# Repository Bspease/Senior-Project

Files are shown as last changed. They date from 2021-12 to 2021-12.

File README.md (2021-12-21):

# Senior-Project

“The Traveling Musician” is the name of the device that travels up and down any piano and plays music. After setting it up, the traveler will start playing the song programmed into it after a
button press until the song has been completed.

This was my 2021 Summer-Fall Senior Project to create a musical device that can play a piano to some degree.

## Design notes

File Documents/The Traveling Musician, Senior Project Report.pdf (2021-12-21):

The Traveling Musician

A Senior Project Report

presented to

the Faculty of California Polytechnic State University

San Luis Obispo

In Partial Fulfillment

of the Requirements for the Degree

Bachelor of Science in Computer Engineering

By

Brian Pease

December 2021

## Table of Contents

Abstract | 3
Introduction | 4
Stakeholders | 4
Project Goals and Objectives | 4
Project Deliverables | 5
Project Outcomes | 5
Background | 5
Formal Project Definition | 6
Customer Requirements | 6
Engineering Requirements | 6
Customer Personas | 7
Use Case | 8
Design | 8
Base | 8
Runner | 10
Software | 14
System Testing and Analysis | 15
Conclusion and Future Work | 17
Reflection | 17
Bibliography | 19

Appendix | 20
Analysis of Senior Project Design | 20
Summary of Functional Requirements | 20
Primary Constraints | 20
Economic | 21
Original Estimated Cost | 21
Final Component Cost | 22
Final Bill For All Components | 22
Original Estimated Development Time | 23
Actual Development Time | 24
If manufactured on a commercial basis | 24
Manufacturability | 24
Sustainability | 25
Ethical | 25
Health and Safety | 25
Social and Political | 26
Development | 26

# Abstract

“The Traveling Musician” is the name of the device that travels up and down any piano and

plays music. After setting it up, the traveler will start playing the song programmed into it after a

button press until the song has been completed. Pressing the button again will have it repeat.

# Introduction

Musical instruments such as pianos, have periods of time of unuse. Whether this is because of

work, family, or time, pianos have downtime. This product serves to utilize the piano when it’s

not in use, to act more as background noise. There are pianos that can self-play, though this

product would be a cheaper alternative aimed for pianos that do not have this function.

## Stakeholders

Customers that would be potentially interested in this would be people who have mostly unused

pianos and would like to have background music without having to spend a lot for their piano to

be converted to a self-playing piano. The product could be used in smaller restaurants or within

family households. These customers would benefit from a cheaper alternative to automated play

and that is not difficult to set up.

## Project Goals and Objectives

The goal would be to play a song:

- Objective 1: Move to the correct key for the note
- Objective 2: Activate the correct solenoid for the note (white or black key)
- Objective 3: Play a simple song that requires little movement
- Objective 4: Play a normal song

## Project Deliverables

The main deliverable would be a device that goes up and down any piano in time to a song and

plays the proper notes.

## Project Outcomes

- More pianos being used in a casual environment
- Piano furniture (never played piano) becomes a feature for a house.
- Could inspire more piano players
- Create live piano music for movie usage without a pianist knowing how to play.

# Background

There has been work in the past that makes pianos “self-playable”, such as Edelweiss’s pianos.

This was accomplished by having solenoids with varying pressure under the striking lever,

mimicking a strike to the key and thus to the piano string. Having these solenoids allows for an

electronic means of activating them such as through an ipad. Prior to the Edelweiss piano, there

was also the pianola, a vacuum based self-playing piano popular in the late 19 century. The

pianola was a much more complex device since it required the use of specifically made paper

rolls for the music and required the mechanisms to be under a slight vacuum. A less extensive

and simpler way is using solenoids.

# Formal Project Definition

## Customer Requirements

- Be reasonably priced
- Easily placed and removed
- Plays a song
- Generally easy to use

## Engineering Requirements

Product Requirements Table

Spec Number | Parameter Description | Requirements | Tolerance | Risk | Compliance
1 | Seconds Off Beat | 1 sec | Max | H | T
2 | Note Travel Error Accuracy | 0.5 mm | Max | H | T
3 | Power | 6 W | Max | L | A, T
4 | Key Range | 7 Keys | Min | L | I

5 | Runner Height Size | 50 mm | Max | L | I
6 | Cost | $60 | Max | L | I
7 | Weight | 200 g | Target | L | T
8 | Set up time | 10 sec | Max | L | I

## Customer Personas

Nathan, a piano enthusiast, wants to explore capabilities not previously thought of in live piano

music. Effectively playing with three hands, the product will act as support to the piano player

Nathan. His students would also use it to ease them into playing with both hands. The robot

acting as the other hand.

Diego, a small business owner, has a piano for his customers but he finds that not many partake

in playing. He has considered hiring a part time musician but due to the covid situation he does

not want to eagerly spend. The device would allow him to have his piano be more in use, and

create a more vibrant environment for his customers.

Samantha, A piano owner, has frequent hangouts with friends, family members, and coworkers.

She loves the presence of a piano but never actually learned to play it. With the device she can

add more flavor to her house without breaking the bank.

## Use Case

The user would place the device on the piano. Situate the arduino and breadboard in front of the

base, ideally on the piano (off of the keys). Plug in the device to a wall outlet and situate the

device on top of a C key with at least the next octave under the wooden base. The user would

then simply press the button on the breadboard after they pre-programmed their songs prior in

order to hear their song.

# Design

The design process was broken up into three different parts. The first part pertained to the

design of the base or structure that held the device; The second was the design of the actual

“runner” or the piece that holds the solenoids and parts; The third was the software design.

## Base

The base was only difficult to design mainly because it had to work for any piano of any size. I

had access to three different pianos during the summer when I was working on this part. A

regularly sized grand piano, electric piano, and a medium sized digital piano (33 keys). The size

and structure differed from each piano drastically. Originally, the first design had some type of

clamping mechanism and was fixed above the piano keys.

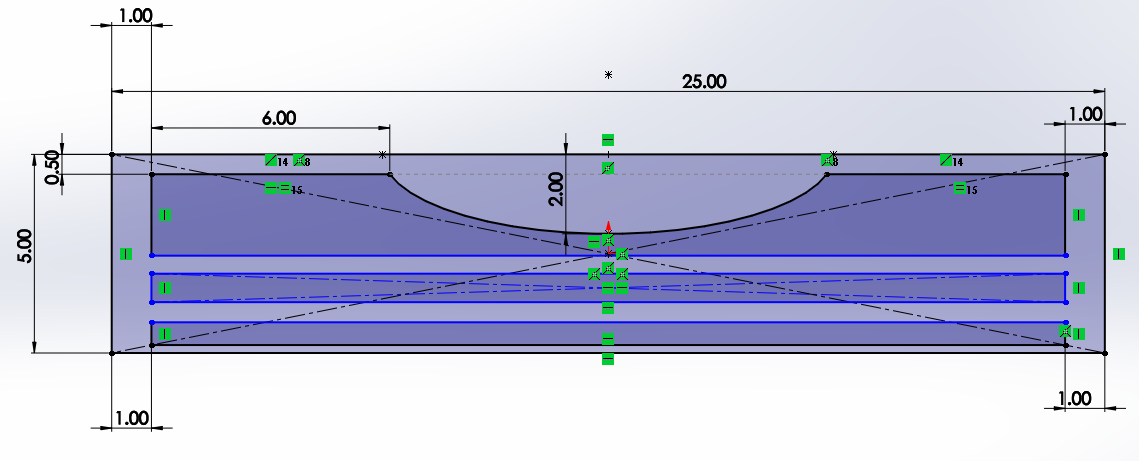
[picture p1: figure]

Figure 1: Original Base Design

Figure 1 was the design of this without the clamping idea. Because I was too focused on having

a physical device rolling up and down the piano I neglected the other, and likely better, ideas

such as having a type of belt system. I primarily didn’t understand how a belt system would work

but looking at a 3d printer would have helped in that endeavor. Eventually the best idea turned

out to be just the rail system, such a simple block of wood, resting on top of the piano keys. As

long as the device wasn’t heavy and the board was long enough, the weight would distribute to

the other keys. The final board is seen on Figure 2.

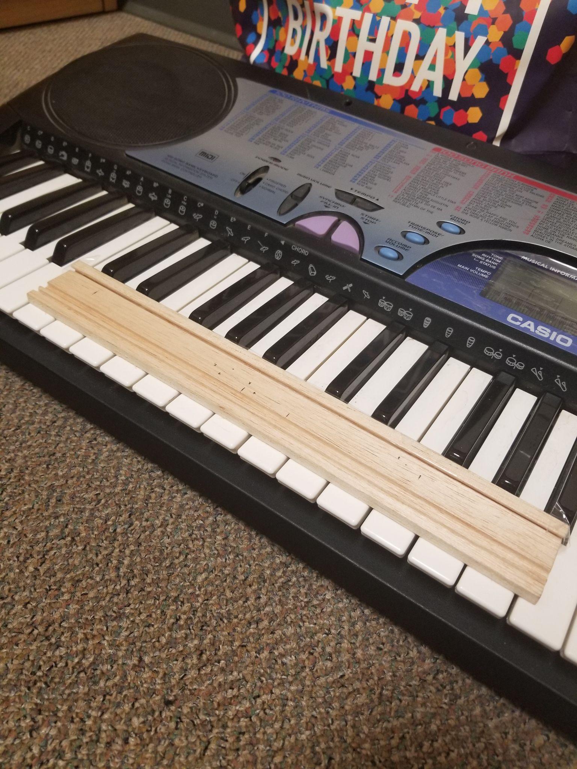
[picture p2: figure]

Figure 2: Final Board

## Runner

The “runner” or the device that moves and holds the solenoids, had multiple iterations. When

designing the runner I arbitrarily added the constraint that the max width of the runner would not

exceed 22 mm, to allow for another possible runner to play the key right next to it. This turned

out to be a bit of a difficult condition to meet considering that the servo on it’s side was 22 mm.

The main idea of the first two iterations was to create a makeshift electromagnet that would

attract a metal that would be attached to some type of lever to press the key in Figure 3, or act

as a regular solenoid in Figure 4.

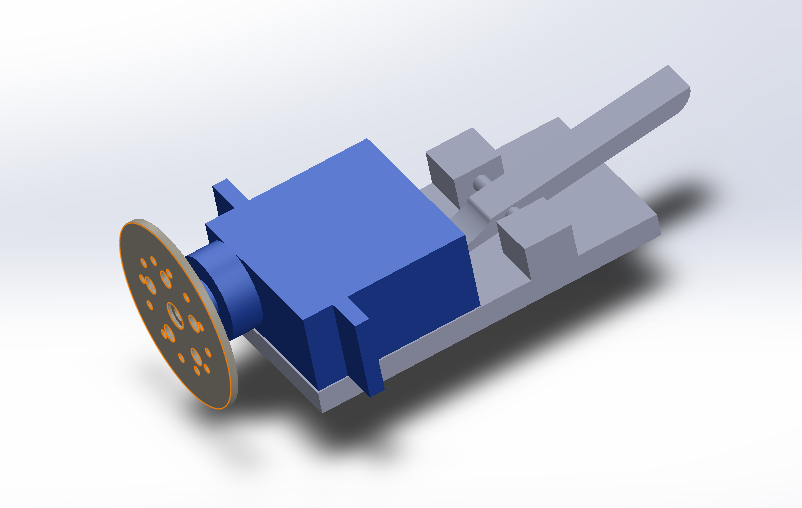
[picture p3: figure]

Figure 3: Runner Iteration 1

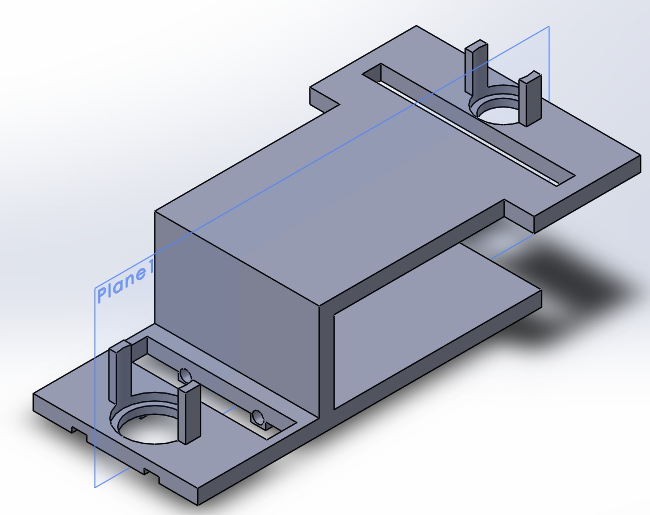
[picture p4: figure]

Figure 4: Runner Iteration 2

The main faults of these two designs was that it did not properly account for the size of the

solenoid and it’s wires to create enough pushing force.

From here, future iterations used actual pre-build solenoids as I did not want my lack of tools at

home to come into consideration.

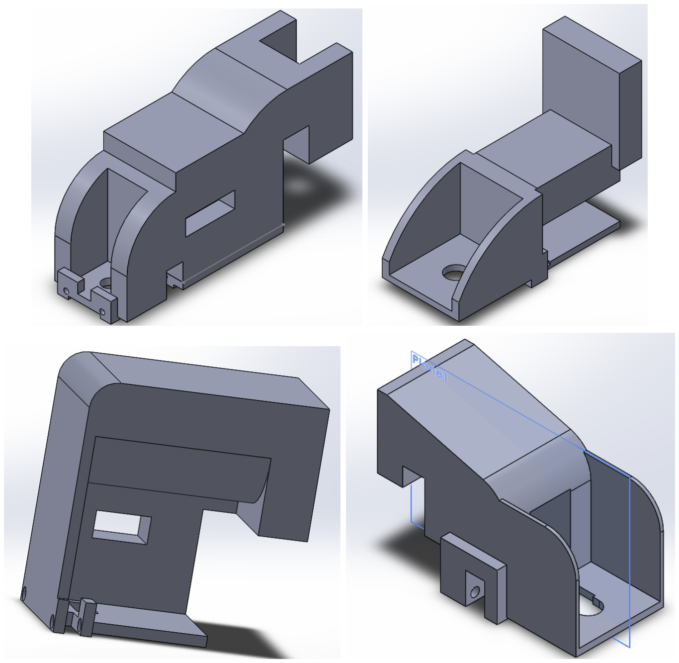
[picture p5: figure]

Figure 5: Runner Iterations 3 (top left), 4 (top right), 5 (bot left), and 6 (bot right)

From Figure 5, iterations 3 (top left), 4 (top right), 5 (bot left), and 6 (bot right) had adjustments

and experimented with new ideas between iterations such as iteration 4 being too long and

housing an insufficient solenoid. This iterative process was the result of trial and error up until

the last iteration, iteration 6 seen in figure 5.

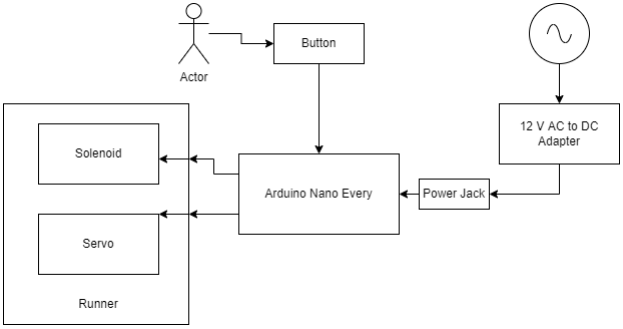
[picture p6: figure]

Figure 6: Hardware Functional Block Design

The hardware functional block design is depicted in Figure 6. Power is supplied through an AC

to DC adapter reducing the voltage to a 12 V DC and this in turn is connected to a power jack

that powers everything including the Arduino Nano Every. The user uses an external button to

start the algorithm and the Arduino signals the servo and solenoid when to turn or deploy. This

continues until the song finishes.

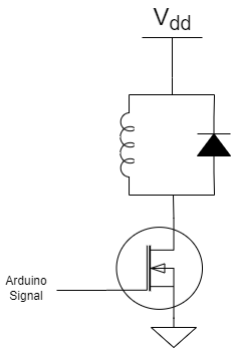
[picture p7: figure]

Figure 7: Solenoid Driver

On top of the runner lies a small breadboard in charge of holding all of the electronics for the

runner such as the n-mosfet, diodes, and power lines. The circuitry (Figure 7) is rather simple so

a small breadboard with 8 lines will suffice. The diode in the illustration acts as a flyback diode

and provides a path back to the source voltage when switching occurs to avoid frying the

mosfet.

## Software

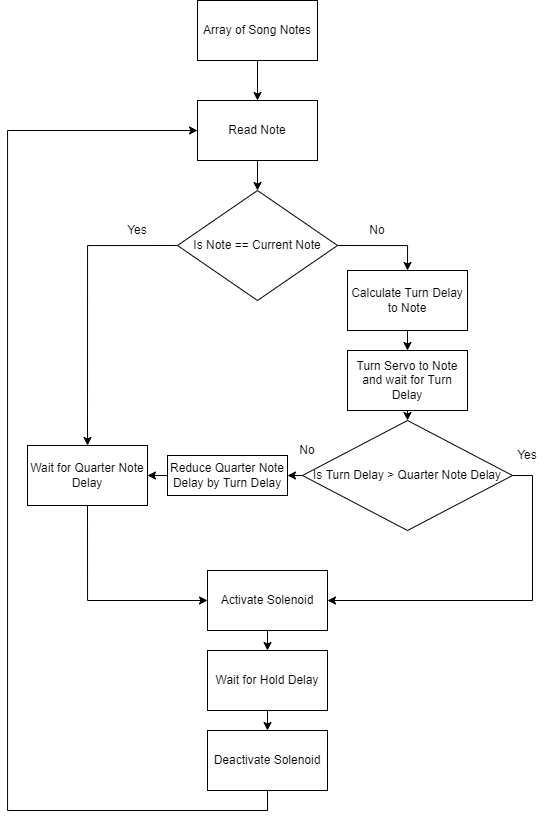
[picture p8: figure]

Figure 8: Software Flowchart

The general path of the software is seen in Figure 8 and is executed after the button is pressed.

The “Quarter Note Delay” and “Hold Delay” are both constants pre-programmed before use.

This software path was originally for the manual option. Since it is hard to read and produce

notes with these delays present, it was designed to be constant so the user only needs to

concern themselves with the notes and quarter notes. The alternative would be an array

formatted to something similar to a song track in .midi files. The design is also scalable. In the

event of an alternative way of movement, replacing the servo, the code will still attempt to

adhere to the timing of the song. The solenoid only activates after the Quarter Note Delay or

Turn Delay depending on which one is larger.

Notes in the song array are formatted as indexes. ‘0’ corresponds to the starting C key and

other positive numbers correspond to the number of keys away from the starting C key. This is

so a person could intuitively write the key they wish to play for a quarter note by simply counting

the number of keys from the start.

The original design was to have the device repeat the songs it was given until told otherwise but

given that the device’s variability error in where it ends up. This requires frequent intervention

thus a continuous play would not be possible for the given setup..

# System Testing and Analysis

Generally, testing was done in stages. The first stage was to adjust the delay times and servo

speeds to a distance consistently with little error. This was a stage that was never really

completed since very slight alterations were eventually found to alter the results. The wires for

instance, if not set right would affect the distance traveled for one side resulting in two different velocities, left and right velocity. This was likely because I neglected weight distribution. The

center of gravity would be roughly around the helper wheels and not the servo, resulting in little

friction and a stationary device. A piece of wood was attached to the other end of the servo with

slots for more weight to draw the center of gravity closer to the servo but this ended up to be

meaningless as testing found. Trial and error eventually led to an error that would still be on the

target key for a small song by tilting the device roughly 2 mm toward the servo.

The second stage was solenoid testing. After ordering the wrong solenoids, the two solenoids

that I was going to use for the black keys and white keys separately met all of the pre-designed

conditions. Their functionality was tested by having the solenoids deploy in tune to a midi

formatted song. This was done by essentially reducing the notes to mean on and off.

The third stage was to combine all of the code and hardware to test for the final product. As

mentioned in the first stage, the biggest issues were variable error in movement and weight

distribution. Unfortunately the solution to the weight distribution and a tolerable movement,

being tilting the device approximately 2 mm required the black key solenoid to push the extra

weight from the tilting effectively making it unable to press the key. However since there is still

an issue with movement, even if the solenoid was able to press the key it would not have been

able to. The black piano keys are essentially smaller targets and would require more precise

movement.

Testing the device essentially came down to trial and error. Especially the 3d printed runner as it

required 6 iterations before it had some form of success.

The final demo was only achievable after extending the range of the white key solenoid,

securing the base to the piano, lowering the black keys with tape slightly to account for the new height of the solenoid (from the tilting), and by raising the ground that the helper wheels were on

by taping the railing.

# Conclusion and Future Work

Overall, the project could have been better. Although it is able to play a simple melody like

“Mary Had a Little Lamb”, it accomplishes it minimally. The software couldn’t be expanded

because of the issues present within the hardware, such as variable error in movement and the

weight imbalance. If the design of having a rc like car were to be kept and improved on, a

separate arduino for bluetooth communications to remove wires, changing the servo to a motor,

and wheel / weight reconsideration would be beneficial to remove some of the issues found

during building the device. Ideally some type of sensor would also be beneficial to help recenter

and ensure keys are properly pressed.

However it would probably be best to completely redesign the device. One that doesn’t require

1-3 mm altercations and be more consistent. The best idea is to have a belt system, one for the

white keys and another for the black keys. Although it would not have the benefit of having

multiple “runners” like the rc car could possibly have, it would be faster, more accurate, and

would not require long wires or another arduino.

## Reflection

My first response to my mistakes was to start the trial and error process earlier so I could find

the issues that arose with my design such as the movement and weight issue. However, I don’t

think that might have helped. Most of my development in regard to the hardware was during the fall where I had access to the university’s tools. I did not have most tools back at home during

the summer and development could only be done digitally. Instead, the best thing I could have

done more extensively was to ask other people’s opinions on my designs since they were the

designs I was most unsure of. I also think this project would have benefited the most being in a

team project since hardware and building were the areas I was least experienced in. It would

have allowed me to focus more on the software side while getting more experience in the other

two.

An aspect I realized about my thinking is that I wanted everything to be perfect in terms of

measurement. This is fine to strive for, but I believe this is one of the reasons the performance

of the final product was affected by some error in fabrication down to 1-3 mm. Another aspect I

realized about myself is that I tended to apply constraints to myself, such as the width limit of 22

mm. These constraints only slowed me from getting to the prototype process, where larger

issues would become more apparent such as the movement. Identifying these potential issues

early allows for more designs to be considered.

In regards to other points, I am glad I got more experience in hardware. I had created solidwork

CAD files and grew familiar with the machinery in Mustang 60 which would help in the future if I

ever would need to use them again.

Overall, I learned a lot from the project. Mainly to get help and bounce ideas off people to find

apparent issues like the weight distribution along with prototyping small things earlier like

movement. That and to apply not so critical conditions after a prototype is made to try to

improve it. This way if there were any issues with the design, it would become known before

more time was spent improving a faulty design.

# Bibliography

“Edelweiss Pianos.” Edelweiss Pianos – Self Playing Pianos | Bespoke Player Pianos, 13 Aug.

2021, https://edelweisspianos.com/self-play/.

“Pianola.” Wikipedia, Wikimedia Foundation, 19 May 2014,

https://simple.wikipedia.org/wiki/Pianola.

# Appendix

## Analysis of Senior Project Design

Please provide the following information regarding your Senior Project and submit to your

advisor along with your final report. Attach additional sheets for your responses to the questions

below.

Project Title: The Travelling Musician | Quarter / Year Submitted: Fall / 2021
Student: (Print Name): Brian Pease | (Sign): ___________________________
Advisor: (Print Name): John Oliver | (Initial): BP | Date: 12/10/2021

### Summary of Functional Requirements

Play a small song on the piano that was manually programmed into the arduino prior.

### Primary Constraints

One constraint was not having any tools available for prototyping in my first quarter of the

project in Summer 2021. A common issue in the project was something to do with hardware. A

3d print that seemingly works on paper proved to not work once actually printed, which is mostly

due to my lack of experience with the medium. I also ran into trouble obtaining the right

solenoid. Finding the right sized solenoid for what I needed also proved to be difficult since none

of the well known vendors seemed to not have small solenoids that had a decent throw. I had to resort to non-engineering websites like Amazon that had less information about a product and

didn’t have any datasheets.

### Economic

Original Estimated Cost

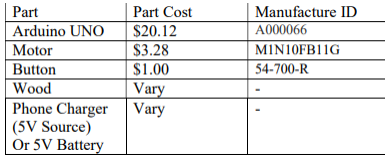
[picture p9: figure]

This was the original estimated cost table before the start of the project when most of its

operations were unknown. The solenoid wasn’t decided on this stage so it was omitted. None of

which are the parts actually used, aside from the button.

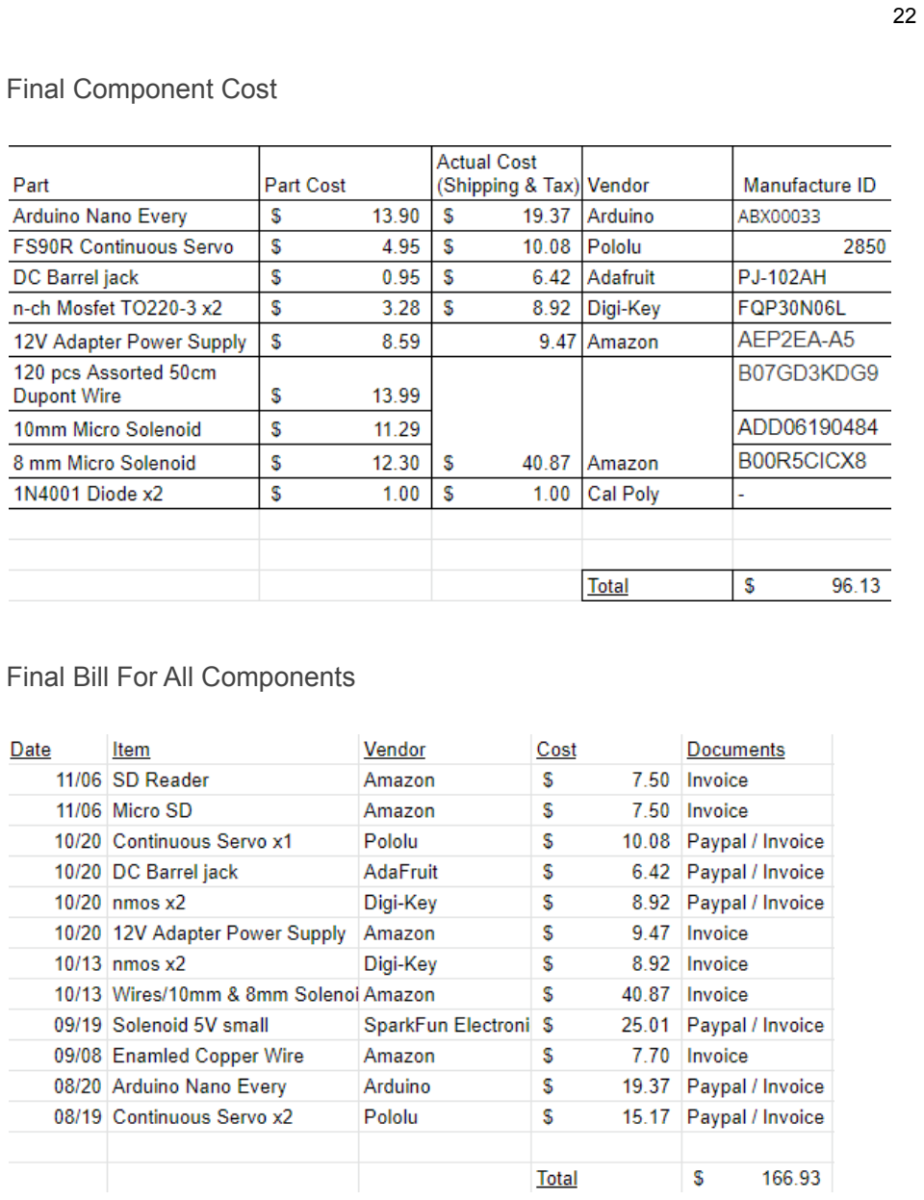
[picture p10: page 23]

### Final Component Cost

### Final Bill For All Components

O

### rigin

### al E

s

### tim

a

t

e

d

D

e

v

### elo

p

m

e

n

t

### Tim

e

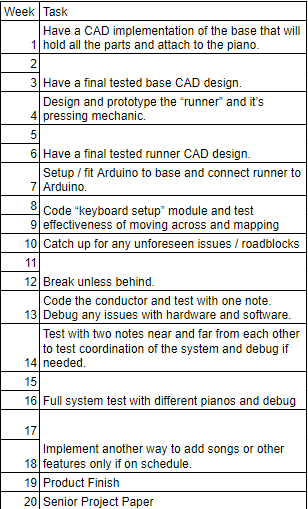
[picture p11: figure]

### Actual Development Time

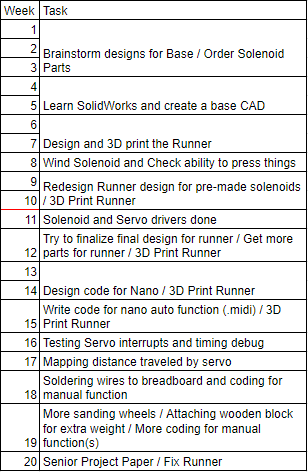
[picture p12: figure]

### If manufactured on a commercial basis

Given the state of the project, the product would not sell in an actual commercial environment.

### Manufacturability

Issues with the 3d printing were fitting issues such as wrong tolerances but that was due to

inexperience in the medium. Other issues were trying to get exact measurements. The base for example with the final CAD model needed to be 6mm high and have a railing with a depth of 3

mm and a width of around 2 mm (had to settle with 3 mm). I also did not know how to create

something with a hatch to secure a part like the servo so I needed to work to create a design

that allowed the devices to slip or be screwed on.

### Sustainability

The device was struggling to stay together since the solenoid and diode wires barely fit into the

small breadboard. It was soldered on but the solder started to come off after moving it around in

boxes and resting it sideways. Additionally the solder that was used was solder with lead

because otherwise it would melt the plastic around the pin. Aside from the lead solder, a tight

fixture that houses the electronics would benefit the lifetime of the product. Upgrading the

design shouldn’t be difficult since most of the components are removable aside from the

wooden piece attached to one of the solenoids. The project tries to use the least amount of

components so it’s not an overuse of resources.

### Ethical

The device can’t really be misused unethically.

### Health and Safety

There are a couple of issues in regards to safety. Most of the components are in open view and

could be re-wired to be dangerous especially since there is a 12v adapter that could go up to

2A. The second issue is less drastic. Since the device has no sensors, it cannot detect issues

and can possibly collide with other objects. The wires could also push objects (if they are light

enough) too. Because of this there is some amount of risk with the project.

### Social and Political

There can be issues with copyright with this device. If the device was acting as it was meant to,

then it is likely (if it got popular) restaurant owners would have to pay for the rights to use it.

Other than that there are no other social and political considerations.

### Development

I learned about the machinery in Mustang 60 and obtained my red card for the project. However,

I primarily used the table saw, drill press, and belt sander for the project. I learned and

understood .midi files since I wanted to implement them originally. There is also Solidworks and

Cura for 3d printing. I designed all of my 3d prints in solidworks and got used to working with the

software when I did not know how prior. I didn’t learn too much in Cura since I mainly used it to

verify my design and see what support structure would form and what would manually have to

be removed after printing. Most of what I learned was in regards to hardware build and design.

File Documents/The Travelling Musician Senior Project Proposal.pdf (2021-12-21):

The Travelling Musician Senior Project

About:
The project at a minimal is to play the piano a note at a time. The objective is to create a piano safe attachable robot that can play a song by pressing each note one at a time in a timely manner. Movement across the keyboard will likely be enabled by a type of rail powered by a motor. Upon start it will first map the keyboard and associate distances to each note, then instruct the runner interface to go to location and activate the press mechanic (not yet defined yet). For the design of the system, there will be an attempt to apply the robot to any type of keyboard with differing number of keys: 32 – 88 keys. Depending on the future unforeseen restrictions or time, a more intuitive way of adding songs to play may be added instead of keeping it in memory.

System Block Diagram:

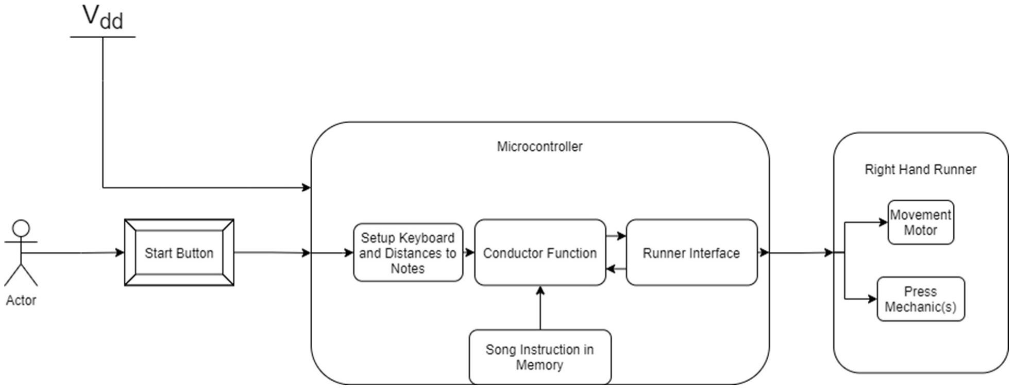
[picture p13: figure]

Possible Parts:
Part | Part Cost | Manufacture ID
Arduino UNO | $20.12 | A000066
Motor | $3.28 | M1N10FB11G
Button | $1.00 | 54-700-R
Wood | Vary | -
Phone Charger (5V Source) Or 5V Battery | Vary | -

Deadlines:
June 25: Have a CAD implementation of the base that will hold all the parts and attach to the piano.
July 9: Have a final tested base CAD design.
July 23: Design and prototype the “runner” and it’s pressing mechanic.
August 6: Have a final tested runner CAD design.
August 13: Setup / fit Arduino to base and connect runner to Arduino.
August 27: Code “keyboard setup” module and test effectiveness of moving across and mapping the piano.
September 3: Catch up for any unforeseen issues / roadblocks.
September 17: Break unless behind.
September 24: Code the conductor and test with one note. Debug any issues with hardware and software.
October 1: Test with two notes near and far from each other to test coordination of the system and debug if needed.
October 15: Full system test with different pianos and debug.
November 26: Implement another way to add songs or other features only if on schedule. November 26: Product Finish.
December 10: Senior Project Paper.

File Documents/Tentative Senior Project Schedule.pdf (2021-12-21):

Tentative Senior Project Schedule

A tentative schedule for the Traveling Musician Project. For a B on this project, the minimum

requirements is to have a robot press song notes on a keyboard at a reasonable pace.

October 8: Solenoid and Servo drivers done

October 15: Finalization for runner / Get parts for new runner

October 29: Design code for Nano / Mapping distance to piano keys

November 5: Test and adjust precision of piano

November 12: Play a manually entered song

November 26: Support for another runner

December 3: Extra or Catch up

December 10: Senior Project Paper

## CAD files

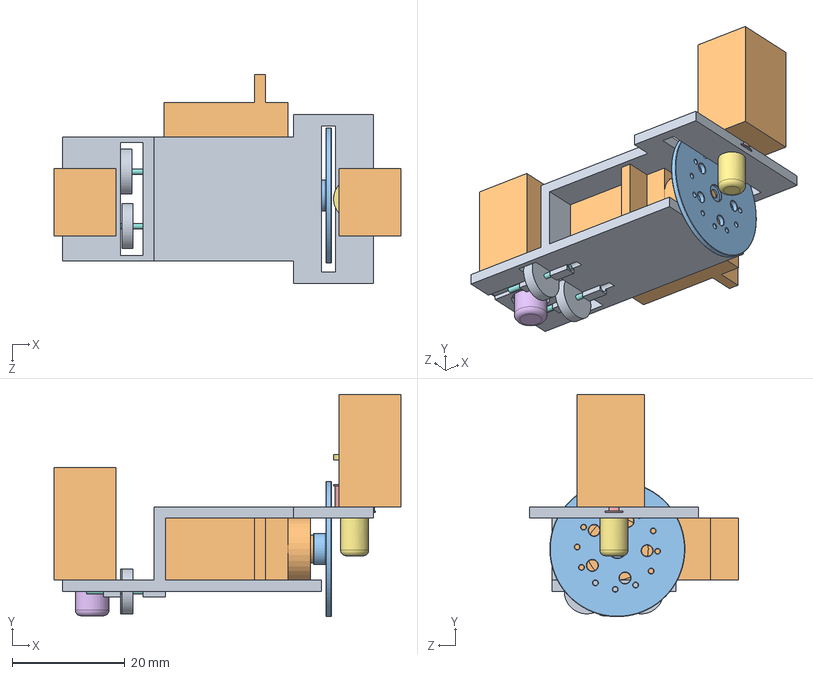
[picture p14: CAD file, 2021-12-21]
Hardware/Next_Iteration/AltAssem.SLDASM
61.6 x 39.5 x 37.1 mm
RunnerAlt
TestServo
Micro sized Servo Mount - Round
6.7Inductor
5.6Inductor
5.14LPress
4.13LPress
0.8Axel x 2
SmallWheel x 2
SolenoidPreBuilt x 2

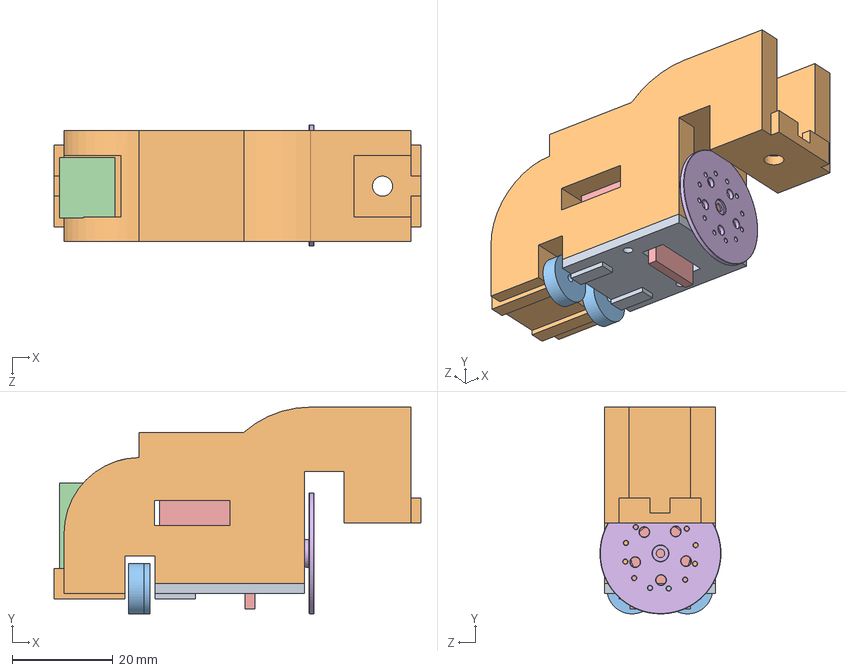
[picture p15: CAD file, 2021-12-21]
Hardware/Next_Iteration/Next_Iteration/Assem1.SLDASM
72.8 x 41.0 x 24.0 mm
SmallWheel x 2
SolenoidPreBuilt
TestServo
Micro sized Servo Mount - Round

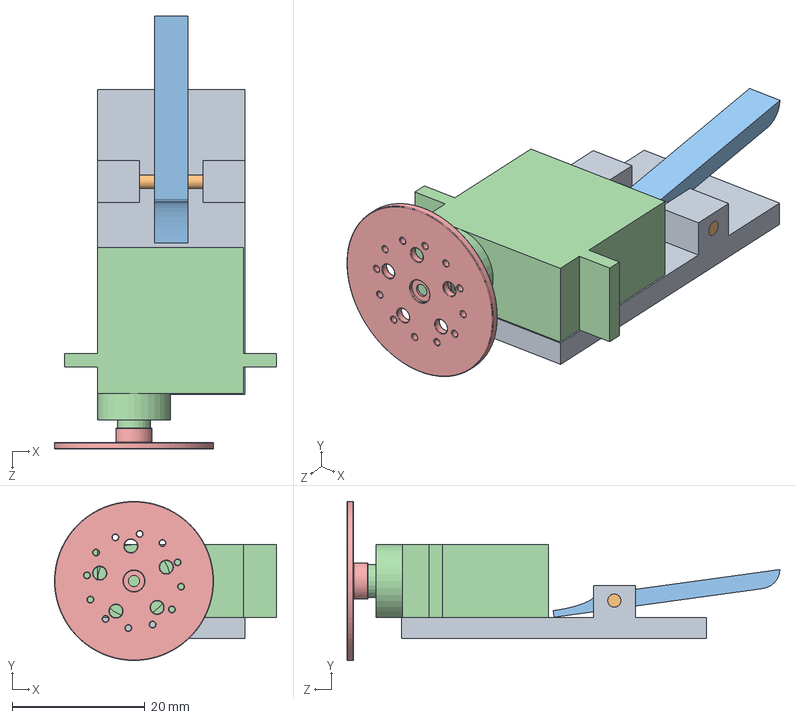
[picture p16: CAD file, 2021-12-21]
Hardware/Runner.SLDASM
33.5 x 24.0 x 65.3 mm
RunnerAct
RunnerAxel
RunnerLever
TestServo
Micro sized Servo Mount - Round

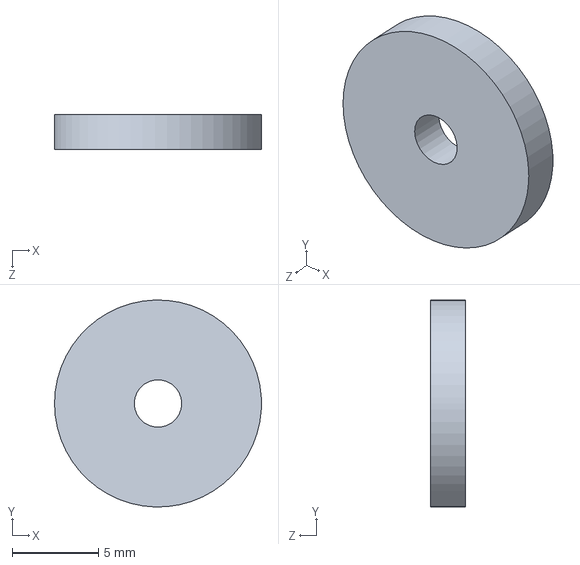
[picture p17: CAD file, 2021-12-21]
Final Hardware Prints/SmallWheel.SLDPRT
12.0 x 12.0 x 2.00 mm

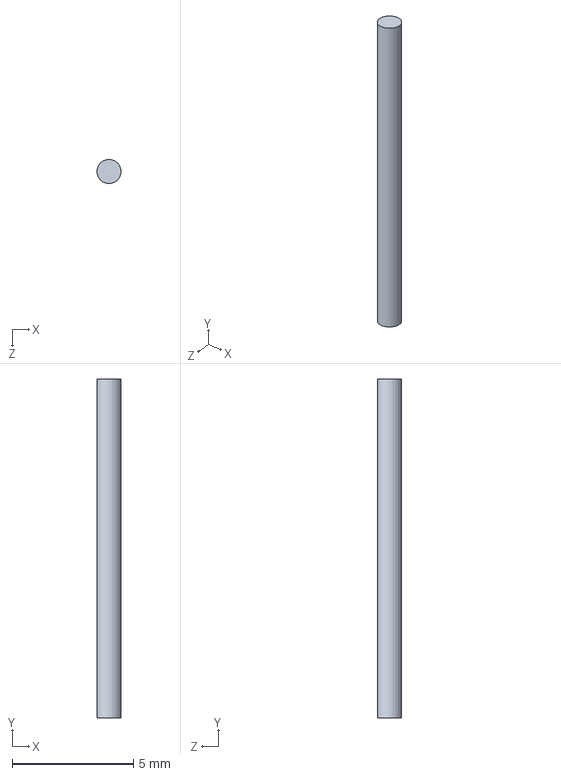
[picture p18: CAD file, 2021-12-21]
Hardware/Next_Iteration/0.8Axel.SLDPRT
1.00 x 14.0 x 1.00 mm

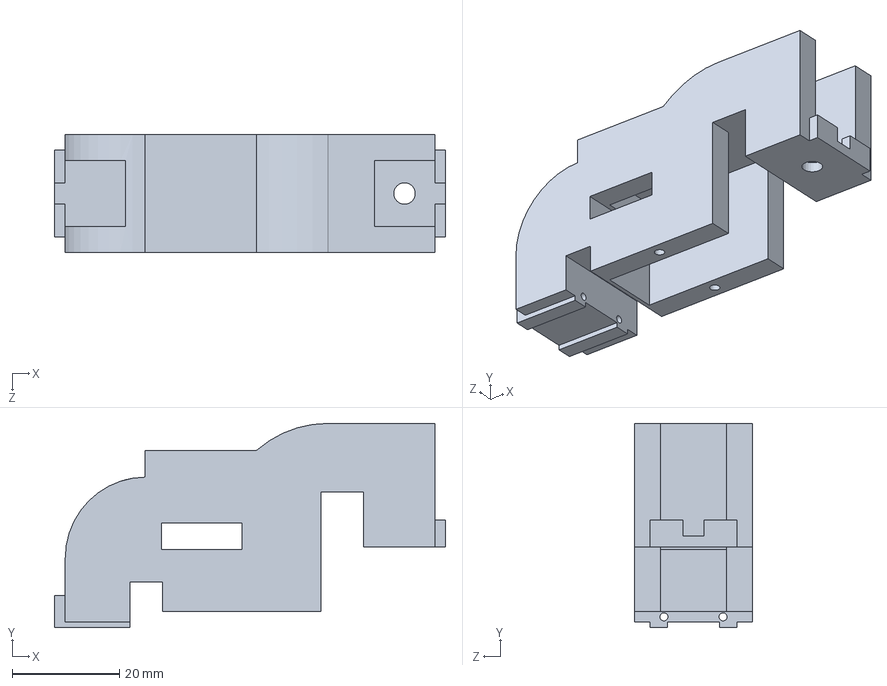
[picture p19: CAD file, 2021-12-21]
Hardware/Next_Iteration/Next_Iteration/Body2.SLDPRT
72.8 x 38.0 x 22.0 mm

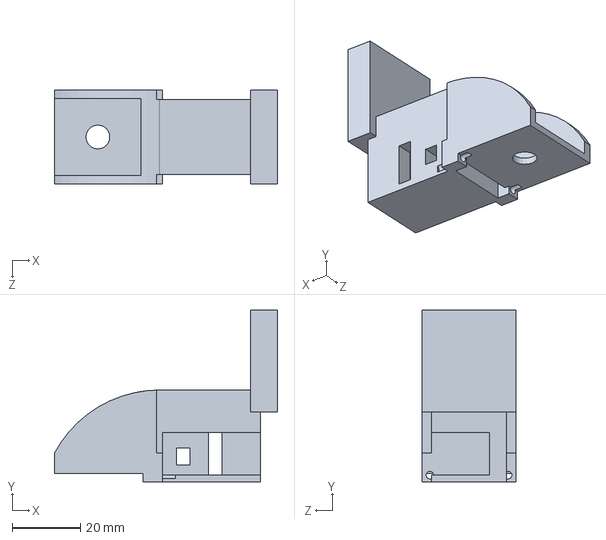
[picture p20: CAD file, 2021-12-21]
Hardware/Next_Iteration/Next_Iteration/Next_Iteration/Runner1.5.SLDPRT
65.6 x 50.5 x 27.5 mm

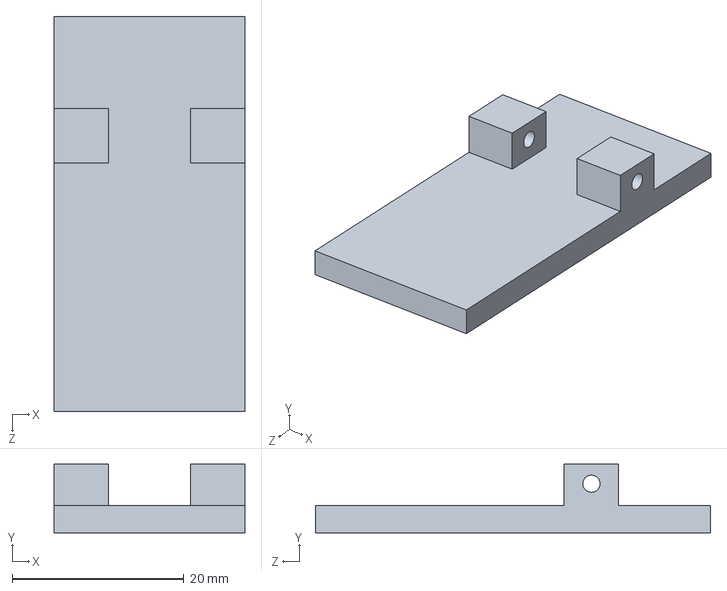
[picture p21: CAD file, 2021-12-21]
Hardware/RunnerAct.SLDPRT
22.2 x 7.98 x 46.0 mm

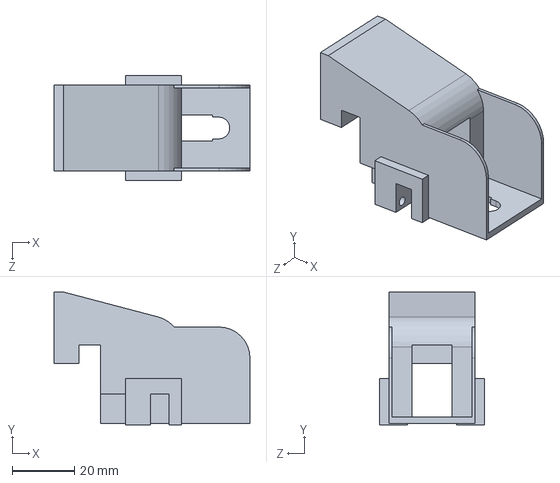
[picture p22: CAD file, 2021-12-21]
Final Hardware Prints/Runner3.SLDPRT
63.0 x 42.8 x 33.8 mm

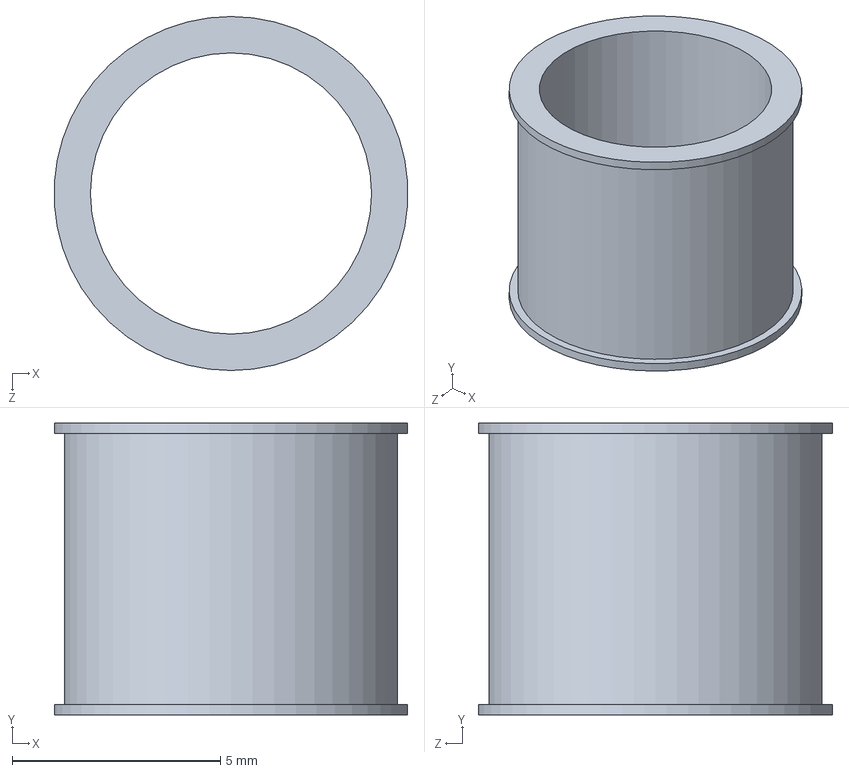
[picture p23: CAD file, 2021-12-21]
Hardware/Next_Iteration/6.7Inductor.SLDPRT
8.48 x 7.00 x 8.50 mm

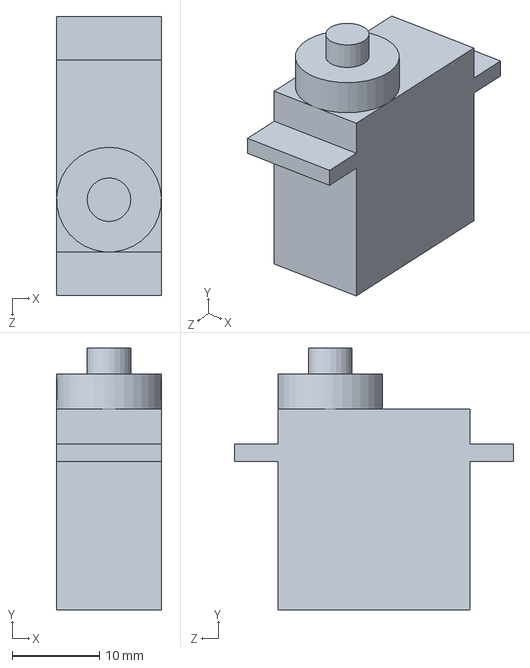
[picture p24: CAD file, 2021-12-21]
Hardware/Next_Iteration/Next_Iteration/Next_Iteration/TestServo.SLDPRT
12.0 x 30.0 x 32.0 mm

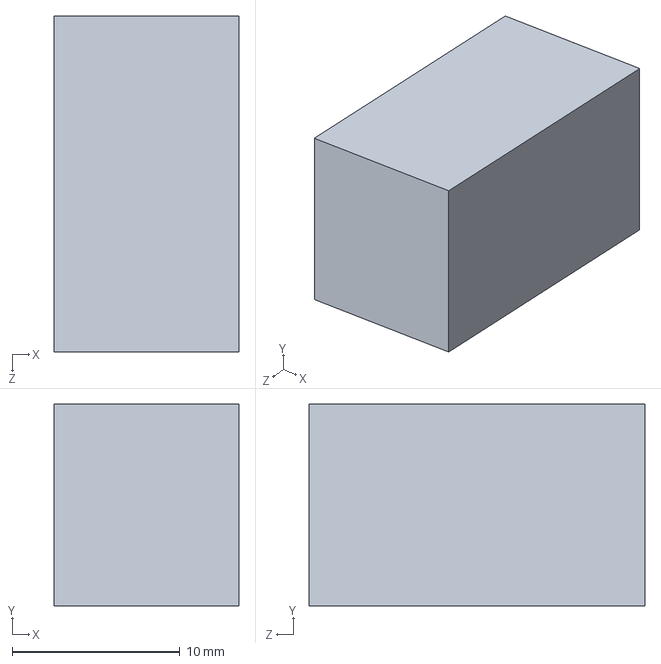
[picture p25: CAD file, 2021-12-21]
Hardware/Next_Iteration/Next_Iteration/SolenoidPreBuilt.SLDPRT
11.0 x 12.0 x 20.0 mm

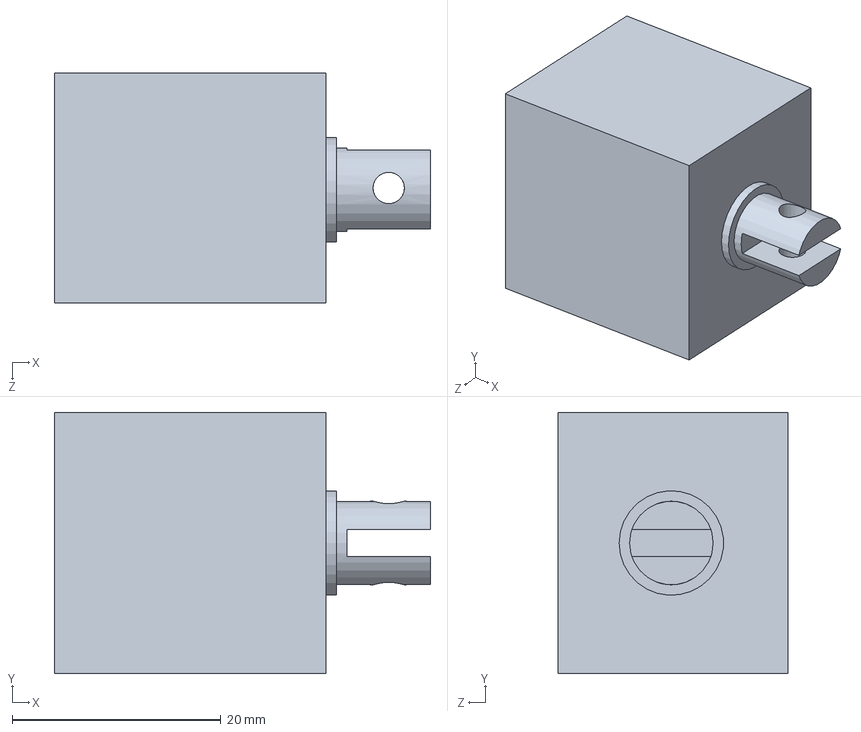
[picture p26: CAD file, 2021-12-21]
Hardware/Solenoid.SLDPRT
36.0 x 25.0 x 22.0 mm

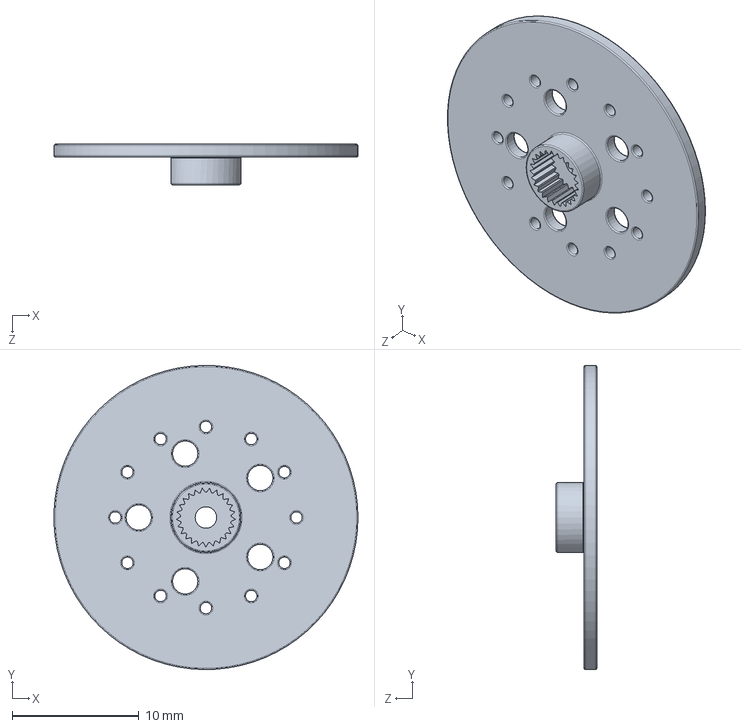
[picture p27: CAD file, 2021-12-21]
Hardware/Micro sized Servo Mount - Round.SLDPRT
24.0 x 24.0 x 3.20 mm

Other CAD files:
Hardware/Next_Iteration/5.6Inductor.SLDPRT
Final Hardware Prints/Runner3.STL
Final Hardware Prints/SmallWheel.STL
Hardware/BaseBasic.SLDPRT
Hardware/BaseSP.SLDPRT
Hardware/Next_Iteration/4.13LPress.SLDPRT
Hardware/Next_Iteration/5.14LPress.SLDPRT
Hardware/Next_Iteration/Next_Iteration/Body1.SLDPRT
Hardware/Next_Iteration/Next_Iteration/Body1.STL
Hardware/Next_Iteration/Next_Iteration/Body2.STL
Hardware/Next_Iteration/Next_Iteration/Next_Iteration/Runner2.SLDPRT
Hardware/Next_Iteration/Next_Iteration/Next_Iteration/Runner3.STL
Hardware/Next_Iteration/Next_Iteration/Next_Iteration/SmallWheel.STL
Hardware/Next_Iteration/Next_Iteration/Runner.SLDPRT
Hardware/Next_Iteration/Next_Iteration/SmallWheel.SLDPRT
Hardware/Next_Iteration/Next_Iteration/SmallWheel.STL
Hardware/Next_Iteration/RunnerAlt.SLDPRT
Hardware/Next_Iteration/SmallWheel.SLDPRT
Hardware/Part1.SLDPRT
Hardware/RunnerAxel.SLDPRT
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

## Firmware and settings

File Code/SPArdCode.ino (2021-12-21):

#include <arduino.h>
#include <Servo.h>

#define KEY_RANGE 14

//Pin Information
#define SOL_PINS 2
#define W_SOL 0
#define B_SOL 1
#define SERVO 9
#define BUTTON 4

#define MS_PER_KEY_RIGHT 280
#define MS_PER_KEY_LEFT 240

// File root;
Servo servo;
// const uint8_t CS = 10;

//Song manual is formatted {note, note, ..., 255}
#define MAN_QUARTER_BEAT_MS 250  //How many ms in one quarter beat
#define MAN_NOTE_HOLD_QB 1
#define MAN_NOTE_DELAY_QB 1

int8_t song_man[] = {2, 1, 0, 1, 2, 2, 2, -1,
                      1, 1, 1, -1, 2, 2, 2, -1,
                      2, 1, 0, 1, 2, 2, 2,
                      2, 1, 1, 2, 1, 0, 127}; //Mary had a little Lamb

const uint8_t sol_pins[] = {2, 3};
uint8_t curr_idx = 0;
volatile uint8_t playF = 0;
uint8_t testF = 0;

void setup() {
  Serial.begin(9600);
  while(!Serial);
  // timer_init();
  servo.attach(SERVO);
  servo.write(90);
  for (int i = 0; i < SOL_PINS; i++)
    pinMode(sol_pins[i], OUTPUT);
  pinMode(BUTTON, INPUT_PULLUP);
}

// power is a number from 0 to 9 that indicates power or speed
// negative numbers reverse the direction.
void turn(int8_t power) {
  uint8_t num = 90 + (10 * (power % 10));
  servo.write(num);
}

int getTurnTime(uint8_t target_i) {
  int dif = target_i - curr_idx;
  if (dif > 0)
    return dif * MS_PER_KEY_RIGHT;
  else
    return dif * MS_PER_KEY_LEFT;
}

//Move servo to note location and activate solenoid if white key
void playNote(uint8_t note, uint8_t var, int delay_ms) {
  uint8_t idx = note;
  int turn_time;

  if (idx >= 0 && idx < KEY_RANGE)
  {
    //Move to Note
    if (curr_idx != idx)
    {
      turn_time = getTurnTime(idx);
      if (turn_time > 0)
        turn(4);
      else
        turn(-4);
      turn_time = abs(turn_time);
      delay(turn_time);
      turn(0);
      if (delay_ms > turn_time)
        delay_ms -= turn_time;
    }
    delay(delay_ms);
    curr_idx = idx;
    digitalWrite(sol_pins[W_SOL], var);
  }
  else
    delay(delay_ms);
}

void test(int f)
{
  if (f)
  {//Right
    turn(4);
    delay(280);
    turn(0);    
  }
  else
  {//Left
    turn(-4);
    delay(240);
    turn(0); 
  }
}

void playSong_man() {
  int8_t *ptr = song_man;
  int delay_ms = MAN_NOTE_DELAY_QB * MAN_QUARTER_BEAT_MS;
  int hold_ms = MAN_NOTE_HOLD_QB * MAN_QUARTER_BEAT_MS;

  while (*ptr != 127)
  {
    playNote(*ptr, HIGH, delay_ms);
    delay(hold_ms);
    playNote(*ptr, LOW, 0);
    ptr++;
  }
}

void loop() {
  if (digitalRead(BUTTON) == LOW)
  {
    playSong_man();
    while (digitalRead(BUTTON) == LOW);
  }
}
